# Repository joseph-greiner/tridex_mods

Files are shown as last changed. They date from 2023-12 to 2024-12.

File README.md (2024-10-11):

# Tridex Mods

Here are modifications I have made for my Tridex, I decided to gather them into a separate repository as I am not sure what should realistically be merged into the main Tridex repository.

## [Adjustable Carriages](https://github.com/joseph-greiner/tridex_mods/tree/main/adjustable_carriage)

Optional physically adjustable carriages that supports CW2 and Stealtherburner compatible hardware.

## [Docs](https://github.com/joseph-greiner/tridex_mods/tree/main/docs)

<b>frame_and_rails_calc.ods:</b> An easier to understand Tridex frame, rails, and belt calculator. Includes Misumi order numbers for extrusions.<br>
<b>parametric_panels.FCStd:</b> Parametric FreeCAD document that scales the panels for selected bed and parking sizes. Export the sketches as DXF and send off to your preferred seller.

## [Dragon Burner Cowls](https://github.com/joseph-greiner/tridex_mods/tree/main/dragon_burner_cowls)

Remix of [chirpy2605 Dragon Burner](https://github.com/chirpy2605/voron/tree/main/V0/Dragon_Burner) tool head to have identifiers on the front face.

## [Drive Frame Umbilical Mount](https://github.com/joseph-greiner/tridex_mods/tree/main/drive_frames_umbilical_mounts)

Added mounts for PG7 glands to the left and right drive frames.

## [Filament Runout Switch and Umbilical Management](https://github.com/joseph-greiner/tridex_mods/tree/main/filament_runout_umbilical_management)

Filament runout switches that mount to the upper rear frame, combined with some reverse bowden and umbilical management clips. An easy way to tame your tool head wiring and filament.

## [Front Skirts](https://github.com/joseph-greiner/tridex_mods/tree/main/front_skirts)

Addition of Revo nozzle holders and USB access to the front skirt.

## [Printer configuration](https://github.com/joseph-greiner/tridex_mods/tree/main/printer_configuration)

Full set of Klipper IDEX macros to enable full use of your printer with minimal configuration on your part. Works best with my Prusa Slicer configuration.

## [Slicer Configuration](https://github.com/joseph-greiner/tridex_mods/tree/main/slicer_configuration)

This is my current Prusa Slicer configuration, including any custom gcode that helps the macros in the printer configuration work.

## [Thick Wiper modification](https://github.com/joseph-greiner/tridex_mods/tree/main/thick_wiper_mod)

Modification for the thick wiper on the wiper arm to allow a loop of silicone instead of a block. This allows for easier adjustment for preventing ooze.

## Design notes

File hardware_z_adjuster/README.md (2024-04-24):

# Hardware z adjustment using double tap

This small modification adds hardware adjustable z height adjustment for the T1 carriage. My testing has shown it to be very consistent, even after travelling across hundreds of miles of US interstate.

## Requirements:

<ul>
  <li>The <a href="https://github.com/joseph-greiner/Double-TAP-for-Tridex">Double Tap for Tridex</a> carriages.
  <li>The tap upper for D2HW available <a href="https://github.com/VoronDesign/Voron-Tap/blob/main/STLs/Tap_Upper_D2HW_r8.stl">here</a>, installed on the the T1 tap front.</li>
  <li>The nozzle for T1 MUST be physically lower (closer to the bed) than the nozzle for T0. If your T1 nozzle is higher than T0, you can shim your hot end with a small printed part from above the heat sink, or a metal washer from below. I personally use an M4 washer between the nozzle and heat sink on my Revo setup, the spring that holds the heater keeps it trapped and not falling out if care is taken.
  <li>3 pieces of hardware you probably already have.</li>
</ul>

## Bill of Materials:
<ul>
  <li>1 - M3 heat set insert.</li>
  <li>1 - M3x12 SHCS.</li>
  <li>1 - M3x20 SHCS.</li>
  <li>Printed parts. ABS / ASA recommended, standard Voron print settings.</li>
</ul>

## Instructions:
<ul>
  <li>Install the heat set into the shuttle piece, from the large side.<br>
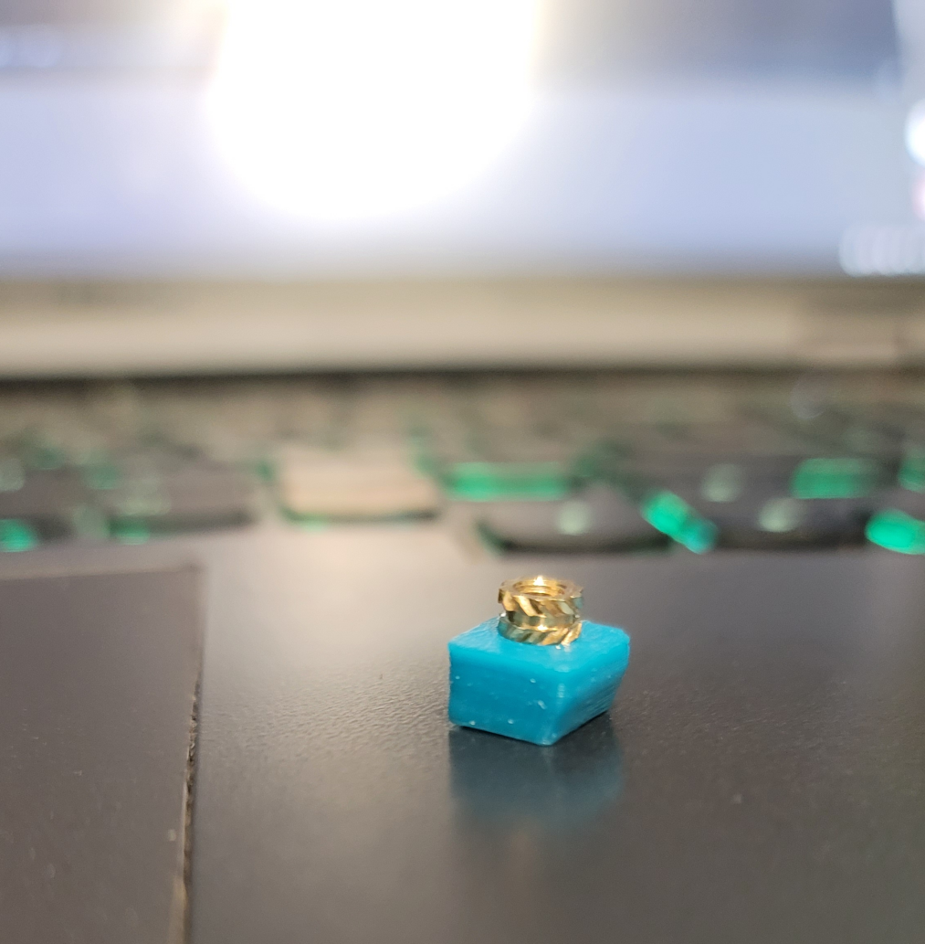
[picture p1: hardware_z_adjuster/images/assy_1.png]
    
  </li>
  <li>Screw the M3x20 fully into the housing, and continue rotating it until it rotates without too much resistance. Basically create some threads with the screw and then strip them out.<br>
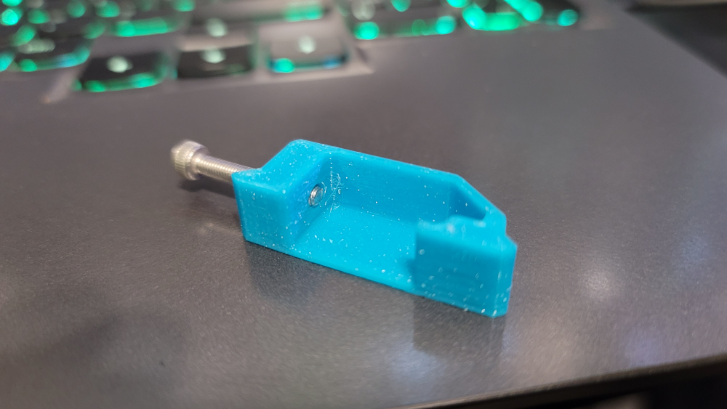
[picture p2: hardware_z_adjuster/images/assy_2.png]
    
  </li>
  <li>Install the shuttle onto the M3x20 screw. Then push the shuttle / screw assembly through the housing a couple times.<br>
      The idea behind this is a push fit of the screw into the plastic housing, it will help it not rotate while printing.<br>
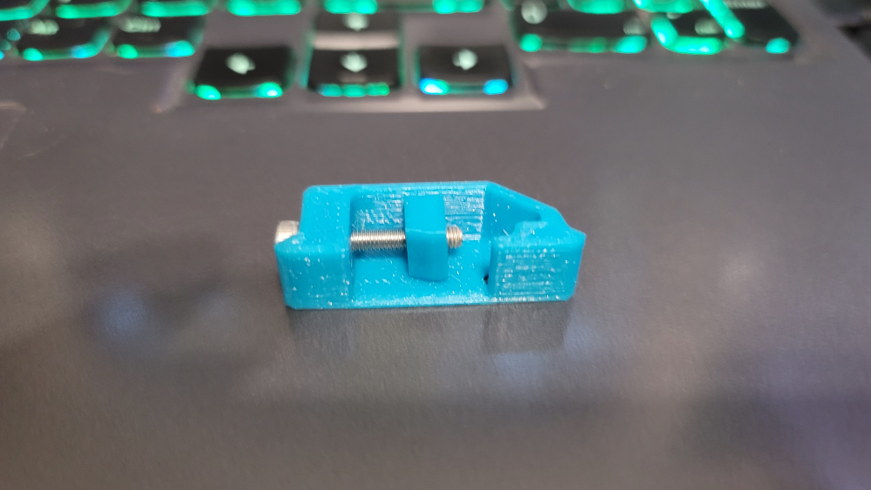
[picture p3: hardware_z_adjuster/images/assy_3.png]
    
  </li>
  <li>The shuttle should move back and forth when turning the screw, but the head of the screw should stay seated on the housing.</li>
  <li>Add the ramp to the assembly then install onto the T1 carriage using the M3x12 in the hole that the Tap switch would mount into.<br>
      The mounting screw should be secure but not tight enough to bind the adjuster.<br>
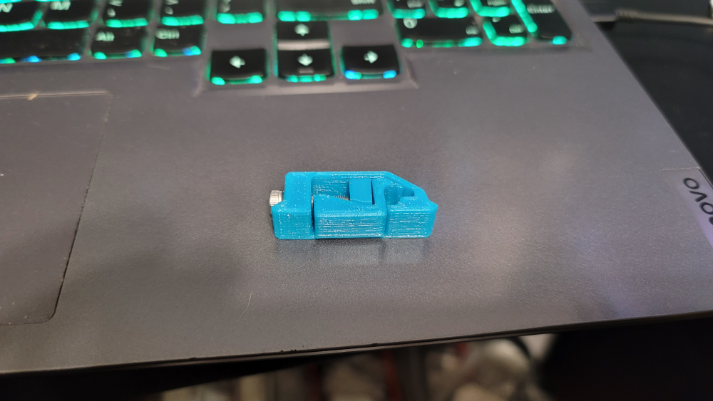
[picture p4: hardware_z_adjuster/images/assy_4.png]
    
  </li>
  
</ul>

## Images:
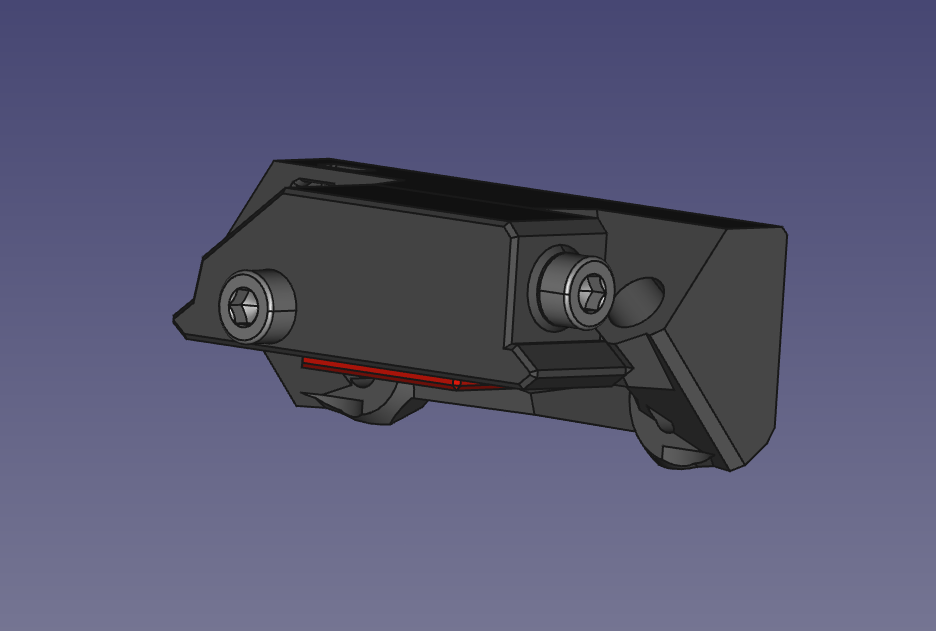
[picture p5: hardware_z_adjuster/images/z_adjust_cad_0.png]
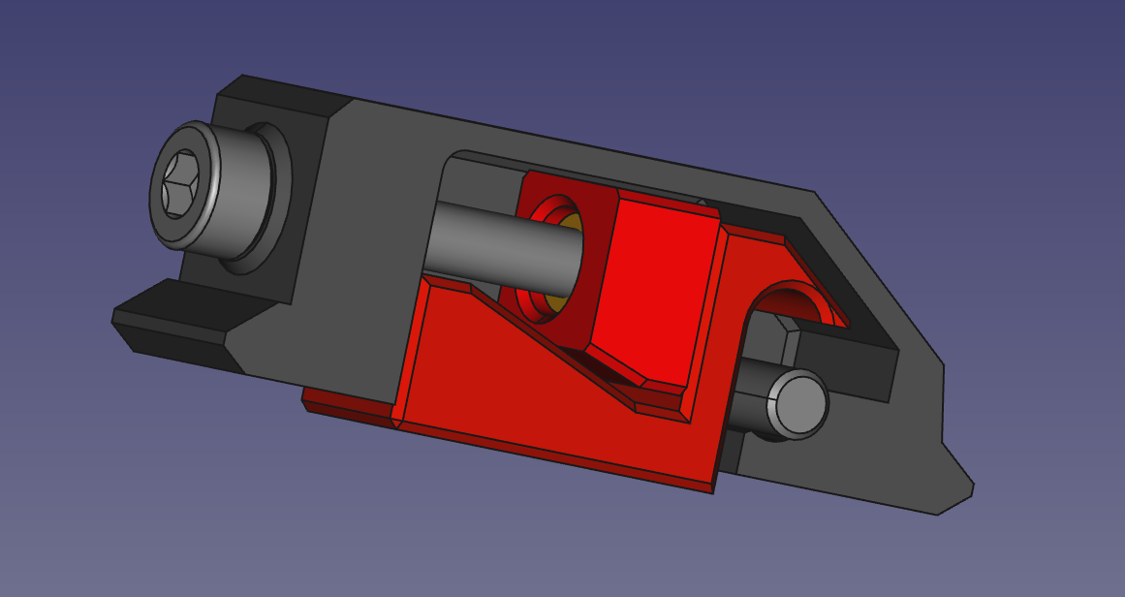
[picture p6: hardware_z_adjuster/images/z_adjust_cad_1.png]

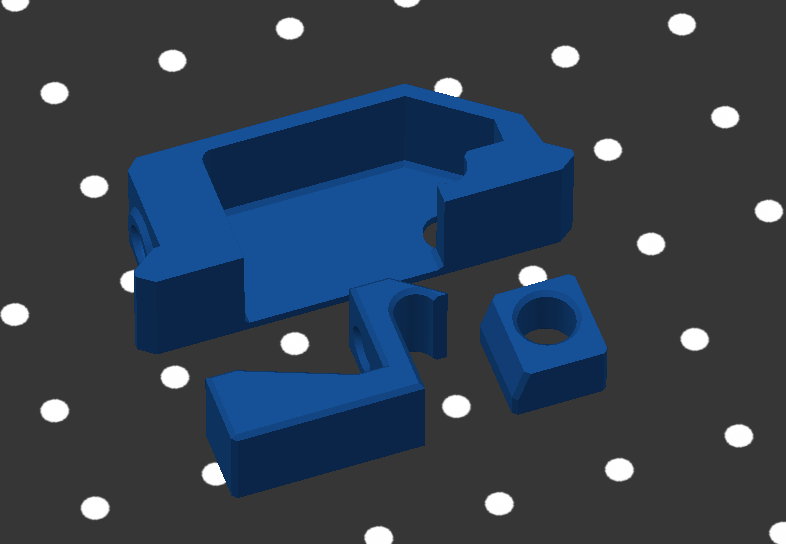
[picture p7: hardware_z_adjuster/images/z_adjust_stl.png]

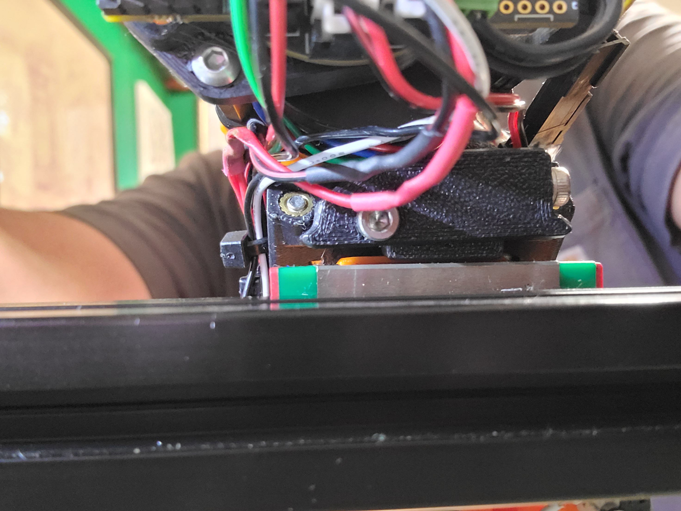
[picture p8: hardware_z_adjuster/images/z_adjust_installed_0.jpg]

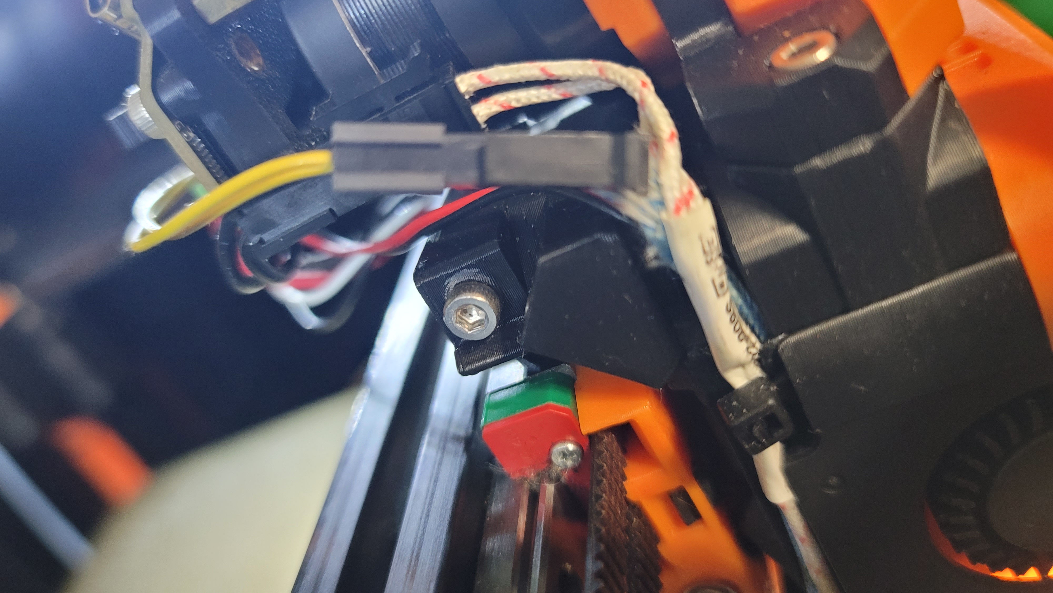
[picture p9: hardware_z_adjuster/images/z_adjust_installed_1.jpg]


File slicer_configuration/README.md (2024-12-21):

Here is the configuration I use for Prusa Slicer and Orca Slicer

# Update for December 20, 2024
Updated the slicer profiles to current releases.<br>
<ul>
    <li>Prusa Slicer: Removed custom gcode on tool change. Prusa Slicer no longer supports wipe tower location placeholders as of version 2.9.0 Alpha.</li>
    <li>Orca Slicer: Updated hacked single tool multimaterial printer to multiple tools. I will add Orca version numbers on the zip file from now on.</li>
</ul>

# Update for June 16, 2024<br>
Added Orca Slicer profiles for Primary, Copy, and Mirror modes. Hopefully the filament profiles are included. These are basic settings and get me good prints on my machine while using my printer configuration. Useable as-is or as a base for modifying for your machine.<br>

When using Copy and Mirror modes, make sure the second filament is the same as what you have in the printer, if set to one filament then it will use that for both extruders.

# Update for April 23, 2024<br>

Corrected copy and mirror mode start g-code to align with new print_start macro. Will no longer get errors when using these modes.<br>

Primary mode start g-code:<br>
<pre>
; M190 S0
; M109 S0 ; uncomment to remove set & wait temp gcode added automatically after this start gcode
print_start print_mode="PRIMARY" t0_starting_temp={first_layer_temperature[0]} t1_starting_temp={first_layer_temperature[1]} ooze_prev={ooze_prevention} initial_tool={initial_extruder}
</pre>

Copy mode start g-code:<br>
<pre>
; M190 S0
; M109 S0 ; uncomment to remove set&wait temp gcode added automatically after this start gcode
print_start print_mode="COPY" t0_starting_temp={first_layer_temperature[0]} t1_starting_temp={first_layer_temperature[1]} t0_printing_temp={temperature[0]} t1_printing_temp={temperature[1]}
</pre>
<br>

Mirror mode start g-code:<br>
<pre>
; M190 S0
; M109 S0 ; uncomment to remove set&wait temp gcode added automatically after this start gcode
print_start print_mode="MIRROR" t0_starting_temp={first_layer_temperature[0]} t1_starting_temp={first_layer_temperature[1]} t0_printing_temp={temperature[0]} t1_printing_temp={temperature[1]}
</pre>
<br>

It has 3 Tridex printers,
Primary mode, Copy mode, and Mirror mode. All have 0.4 nozzles, the only change is the start gcode and custom tool change gcode.

The bed size is 300x300. Adjust for your bed size.

There are two print profile, Quality and Speed.

bed_textures contains the images I use in Prusa Slicer for my bed textures. The PNG files are what you should use in Prusa Slicer, the SVG files are the editable source files for the textures that can be easily edited in Inkscape.

Updated December 4, 2023

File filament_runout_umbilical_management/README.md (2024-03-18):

# Filament runout Switch and umbilical management.
 This is a filament runout switch integrated into the umbilical and bowden management that I use.<p>

 Each filament switch requires the following (each):
 <ul>
    <li>2x ECAS fittings, <a href="https://www.amazon.com/Pneumatic-Connector-Extruder-Fittings-Accessories/dp/B099FG52D4/ref=sr_1_4?sr=8-4">Amazon Link</a></li>
    <li>1x microswitch, wired for normally open. This is usually the two pins next to each other above the switch button. <a href=https://www.amazon.com/DAOKI-Switch-Momentary-Button-Arduino/dp/B07YKH3TDR/ref=sr_1_9?sr=8-9>Amazon link</a></li>
    <li>1x 683ZZ bearing, <a href="https://www.amazon.com/uxcell-Bearing-Double-Shielded-Bearings/dp/B07FW18RQY/ref=sr_1_5?sr=8-5 "> Amazon Link</a>
    <li>1x bowden_mount_upper_filament_switrch printed part.
    <li>1x M3 t-nut</li>
    <li>1x M3-8 SHCS</li>
    <li>2x M2-10 SHCS</li>
 </ul>

The bowden_mount_lower only requires one M3 t-nut and one M3-8 SHCS for mounting to the frame.

 The filament switch part collects the bowden from the filament spool and the umbilical wiring from the frame. The bowden_clip parts trap the bowden tube in the smaller part and uses the bushing (printed in flexible filament) to grab the wiring. You can use a negative volume in Prusa Slicer to make the hole in the bushing the correct size for your umbilical wiring. I use 3 bushings and clips for each tool head on my setup. See images below.

<p>
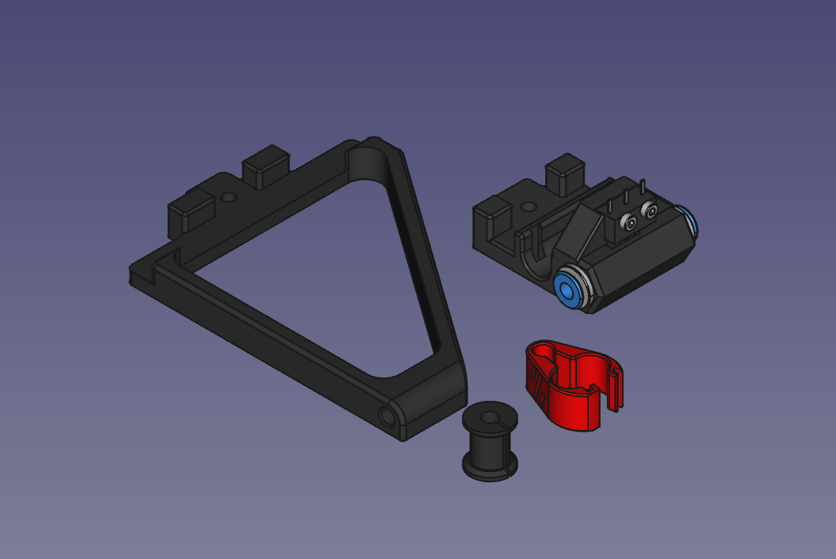
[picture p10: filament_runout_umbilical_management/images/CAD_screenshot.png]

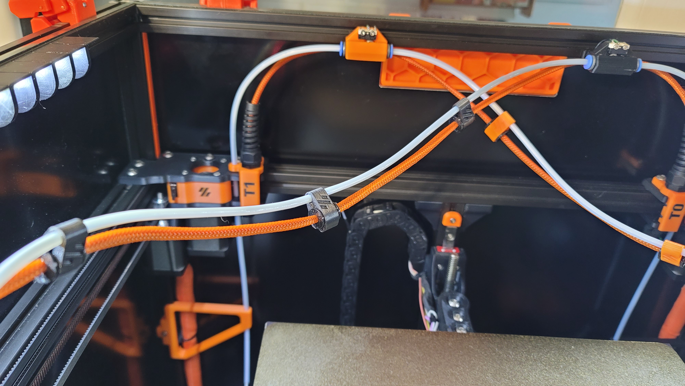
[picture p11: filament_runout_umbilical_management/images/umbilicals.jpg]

<p>
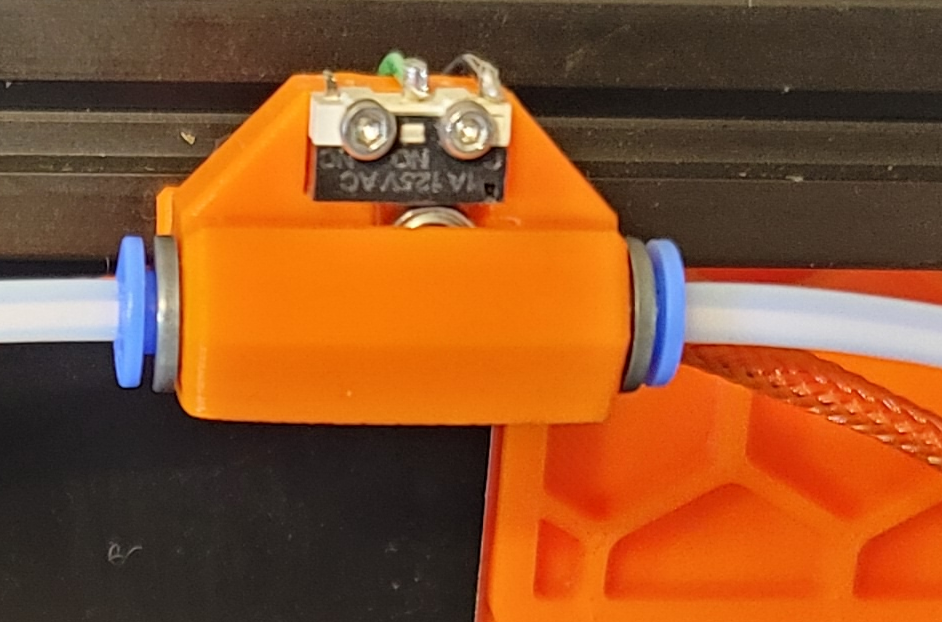
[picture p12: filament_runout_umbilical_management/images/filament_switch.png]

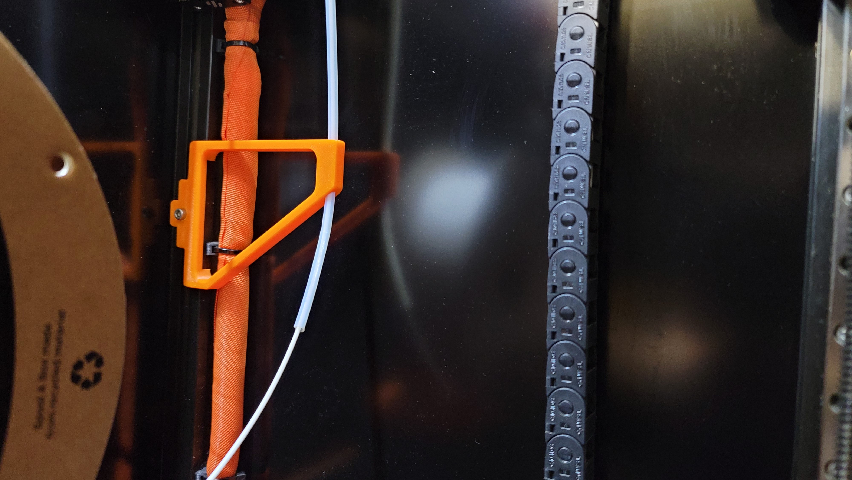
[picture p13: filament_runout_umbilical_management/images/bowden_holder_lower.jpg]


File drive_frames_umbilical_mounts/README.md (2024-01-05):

# Drive frames with umbilical mounts
 Replacement drive frames for Tridex with a PG7 mount and passthrough for a bowden tube.<p>

 Each PG7 mount piece has a blank version and a version that labels that side with the tool head number. T0 is on the right because that is the location of the x_stepper. T1 is on the left because the dual_carriage stepper is on that side. Additionally with the spools mounted on the inside of the chamber, I found it best for the bowden routing to have them setup this way. Spool on the left side goes to the tool head on the right and vice versa.<p>

 The [a]_drive_frame_mid.stl is unchanged from the standard Tridex files, but I added an insert for the Voron logo so if they are printed on a printer with multi-color abilities they can be printed that way.<p>

 Getting the inserts lined up did not work well for me when exporting raw STL files, so I lined them up in Prusa Slicer and saved the projects as .3mf files for ease of use.<p>

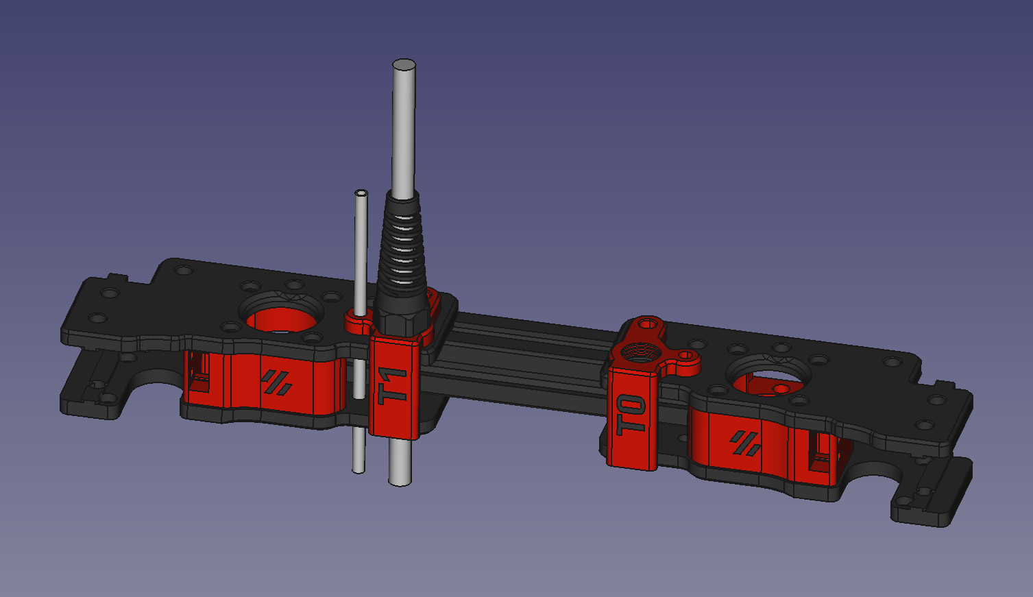
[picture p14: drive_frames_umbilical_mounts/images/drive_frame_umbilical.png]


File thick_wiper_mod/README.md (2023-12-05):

# Thick Wiper modifications
 This allows for a loop of silicone pad rather than a stack. It makes it easier to position the pad under the nozzle to prevent oozing while parked.



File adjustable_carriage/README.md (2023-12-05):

# Adjustable carriages for Tridex
 Replacement carriages for Tridex with a physical adjustment.

The mounting on the carraiges are an exact replacement for the CW2 and Stealthburner mounts, so any CW2 compatable tool head will mount on this. The carriage fits any probe mount that fits on the stock carriage. The tool mounting is approximately 5mm towards the Y minimum direction from the stock carriage. So there may be some loss of travel along the Y axis.

The carriage portion could be used with any tool mount desired, all it needs is a dovetail on the rear that slides into the carriage with a light press fit (see the CAD for dimensions). Also in order to have adjustment, a provision is needed so the lever pushes down on the MGN12 carriage.

The design works well with [Double Tap](https://github.com/ShadowSteve1/Double-TAP-for-Tridex) installed on T0 for probing, as the tool mounting plane is designed to match up with it along the Y axis.

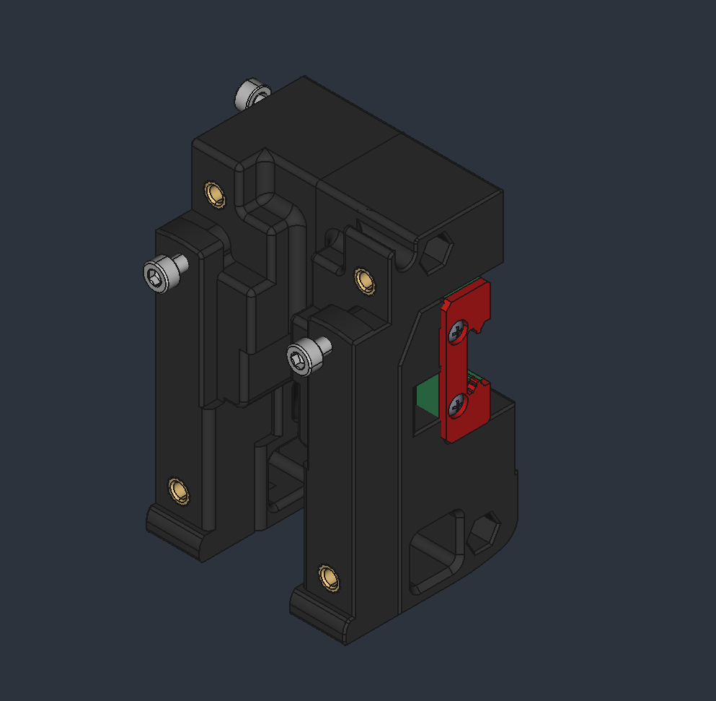
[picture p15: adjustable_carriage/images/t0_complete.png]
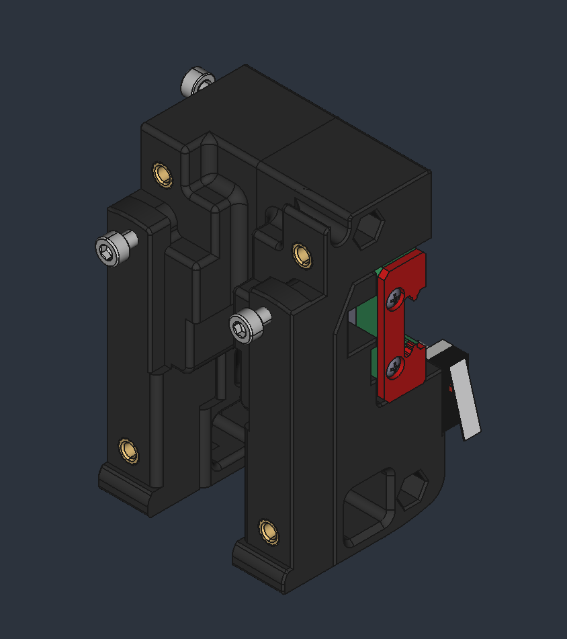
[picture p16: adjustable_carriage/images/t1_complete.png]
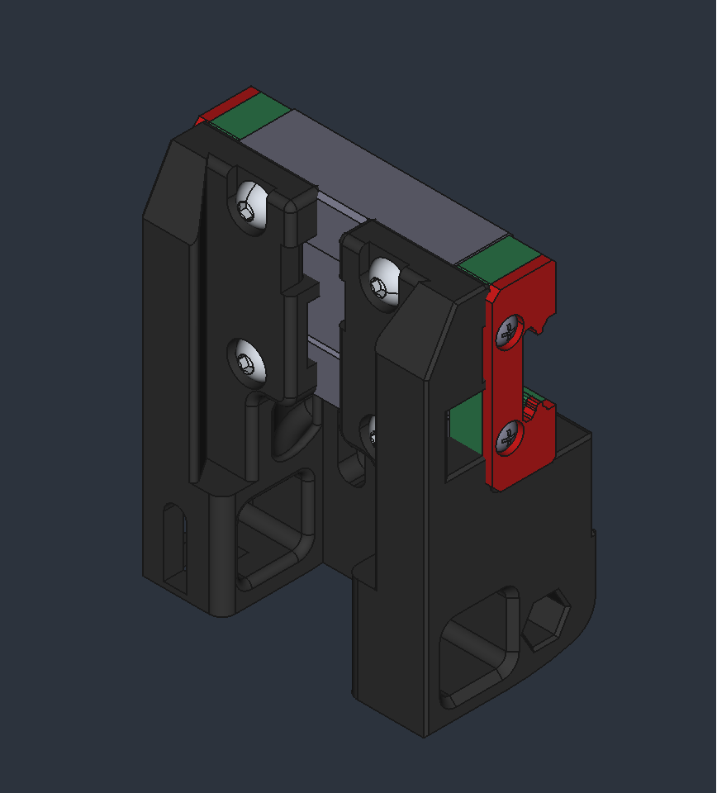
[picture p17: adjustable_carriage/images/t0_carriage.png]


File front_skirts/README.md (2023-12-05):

# Front Skirt modifications
 Two of the revo_nozzle_holder_skirt sections fit in the front of the Tridex when using Trident 250 front skirts. This takes up all the space for a 250 build Tridex, a 300 build will have a gap large enough for the USB skirt panel. This allows USB extensions to be used to bring the USB from the raspberry Pi out to the skirt for easy access.



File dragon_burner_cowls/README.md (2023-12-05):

# Dragon Burner Cowls
 Remix of [chirpy2605 Dragon Burner](https://github.com/chirpy2605/voron/tree/main/V0/Dragon_Burner) tool head to have identifiers on the front face.

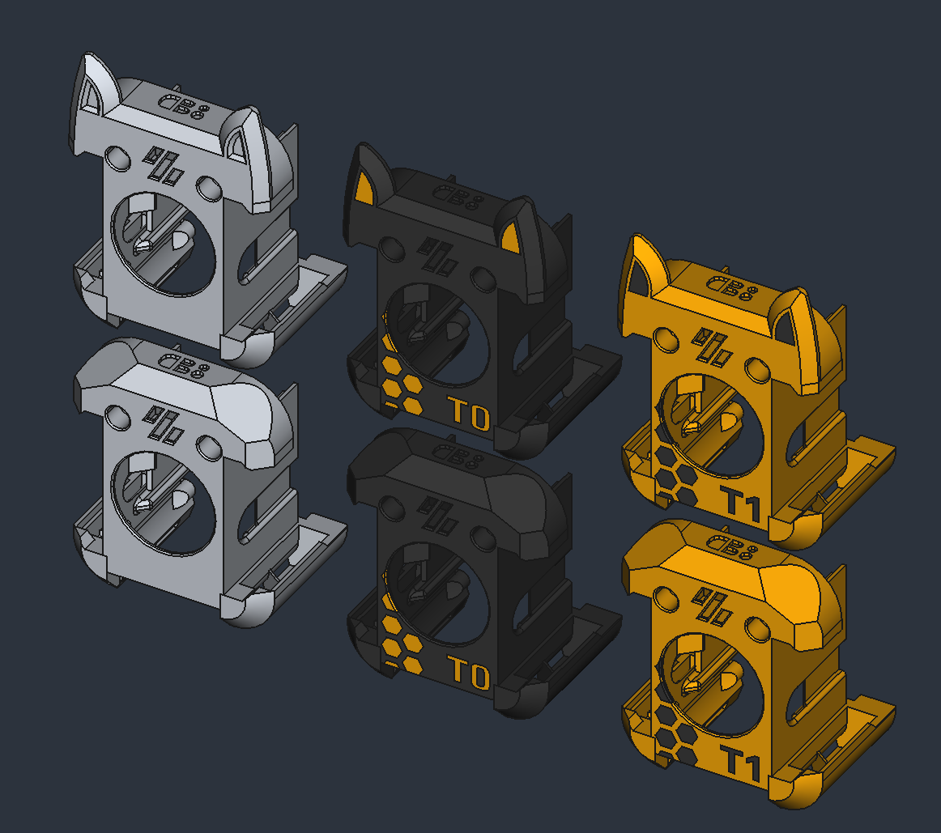
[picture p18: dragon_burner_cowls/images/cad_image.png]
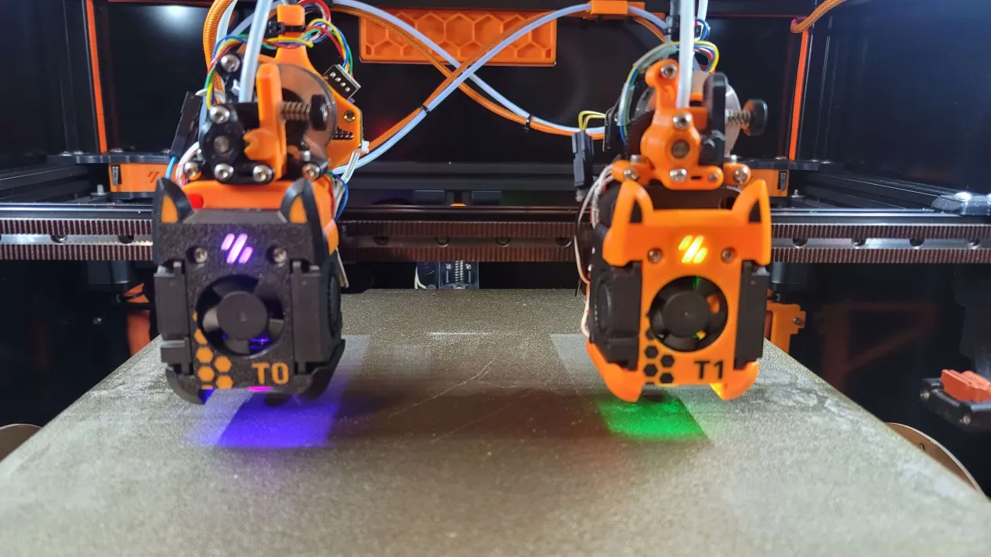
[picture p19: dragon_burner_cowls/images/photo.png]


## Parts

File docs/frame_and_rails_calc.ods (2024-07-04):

Change green cells to desired bed size, Z height, tool width, and parking area in mm
Standard Voron Bed size: | 250 | 250 / 300 / 350 |  |  | Tool head limits:
Z height: | 250 |  |  |  | T0 min X: | -50
Tool Head Width: | 75 | Stealthburner is about 75mm wide |  |  | T0 max X: | 225
Parking Area: | 50 | Standard Parking area is 50mm |  |  | T1 min X: | 25
 |  |  |  |  | T1 max X: | 300
 |  |  |  | Tool head usable area |  | 200
X-Axis MGN12 Rail length: | 400 | mm | Recommend less than 500mm
Y-Axis MGN9 Rail length: | 300 | mm |  |  |  | Total Printer Size (WxDxH):
Z-Axis MGN9 Rail length: | 300 | mm |  |  |  | 510mm Wide (X)
Minimum Belt Length to Buy: | 6 | m | Rounded up to the next whole meter |  |  | 410mm Deep (Y)
 |  |  |  |  |  | 580mm High (Z)
Frame Pieces to Order:
Where used | Qty | Extrusion Type | Length (mm) | Axis | Modifiers | Misumi Order Number
Horizontal (Width-X) | 3 | HFSB5-2020 | 470 | x | TPW | HFSB5-2020-470-TPW
Horizontal (Depth-Y) | 6 | HFSB5-2020 | 370 | y | TPW | HFSB5-2020-370-TPW
Bottom Rear | 1 | HFSB5-2020 | 470 | x | TPW-AH235 | HFSB5-2020-470-TPW-AH235
X axis | 1 | HFSB5-2020 | 430 | x |  | HFSB5-2020-430
Gantry Rear Crossbar | 1 | HFSB5-2020 | 340 | x |  | HFSB5-2020-340
Bed (Width-X) | 1 | HFSB5-2020 | 470 | x | AH235 | HFSB5-2020-470-AH235
Bed (Depth-Y) | 1 | HFSB5-2020 | 232 | y | LTP | HFSB5-2020-232-LTP
Verticals | 4 | HFSB5-2020 | 500 | z | LCP-RCP-AV360 | HFSB5-2020-500-LCP-RCP-AV360
Center Z Vertical | 1 | HFSB5-2020 | 330 | z | LTP | HFSB5-2020-330-LTP
 |  |  |  |  | Extrusion Modifier Legend
 |  |  |  |  | TPW | Tap both ends, M5x0.8
 |  |  |  |  | AH | Access hole, horizontal
 |  |  |  |  | LTP | Left end tap, M5x0.8
 |  |  |  |  | LCP | Left blind joint holes
 |  |  |  |  | RCP | Right blind joint holes
 |  |  |  |  | AV | Access hole, vertical

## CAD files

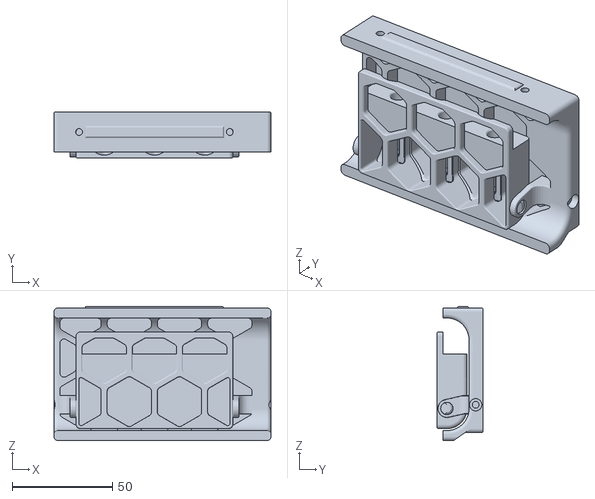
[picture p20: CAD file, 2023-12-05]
front_skirts/STL/revo_nozzle_holder_full.stl
108.0 x 23.0 x 66.8

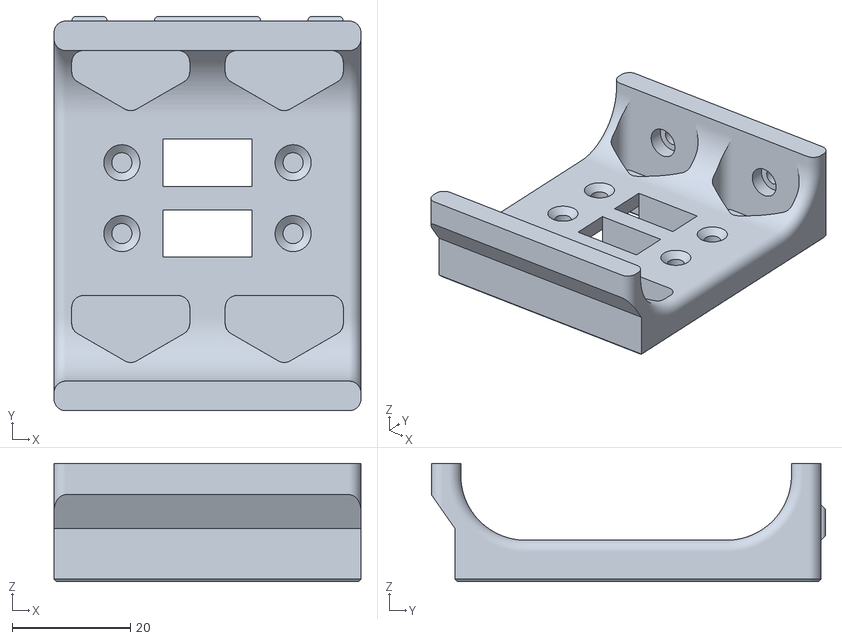
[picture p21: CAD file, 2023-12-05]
front_skirts/STL/usb_panel_full.stl
52.0 x 66.8 x 20.0

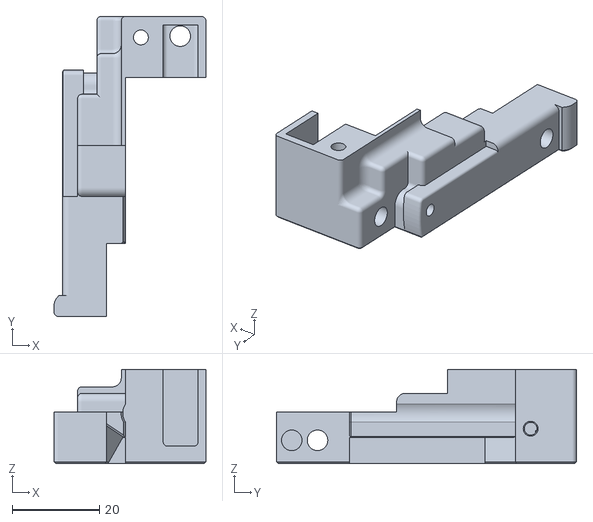
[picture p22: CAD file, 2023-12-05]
adjustable_carriage/STL/ac_tool_mount_left.stl
34.8 x 68.7 x 21.6

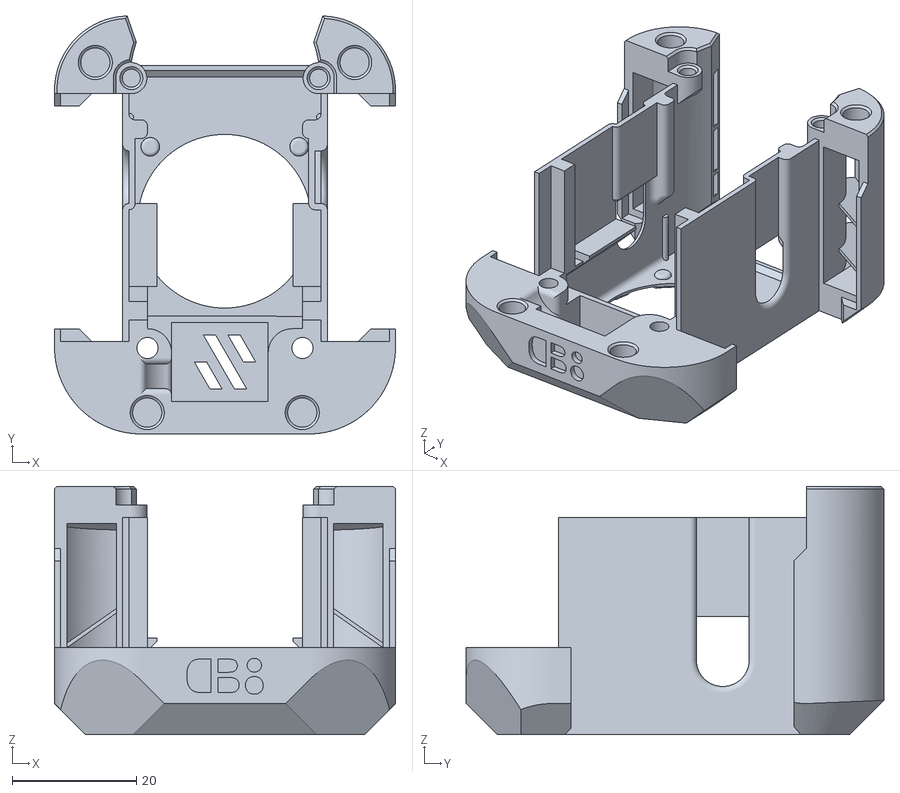
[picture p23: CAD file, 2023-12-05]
dragon_burner_cowls/STL/t0_cowl.stl
55.0 x 67.4 x 40.0

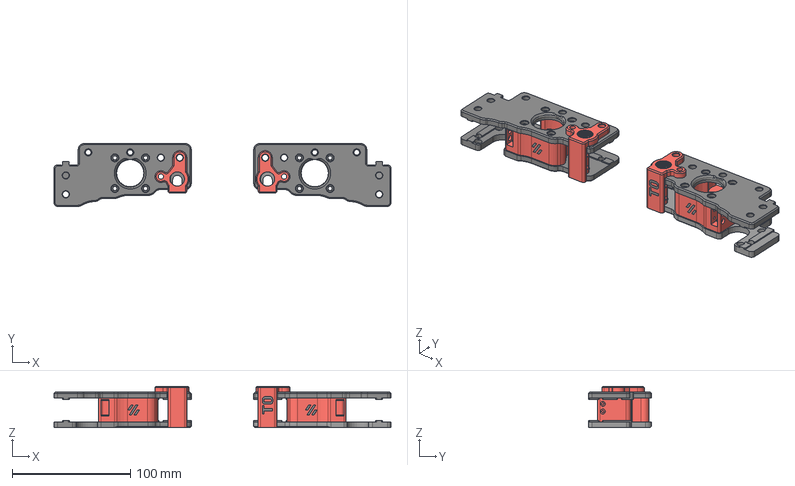
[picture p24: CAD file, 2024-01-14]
drive_frames_umbilical_mounts/CAD/drive_frame_umbilical_mount.step
285.2 x 53.3 x 35.0 mm
drive_frame_left_upper
drive_frame_left_lower
[a]_drive_left_mid
t1_text
voron_logo_insert_left
pg7_mount_left
pg7_mount_left_t1
voron_logo_insert_right
[a]_drive_right_mid
t0_text
drive_frame_right_lower
drive_frame_right_upper
[a]_pg7_mount_right
[a]_pg7_mount_right_t0

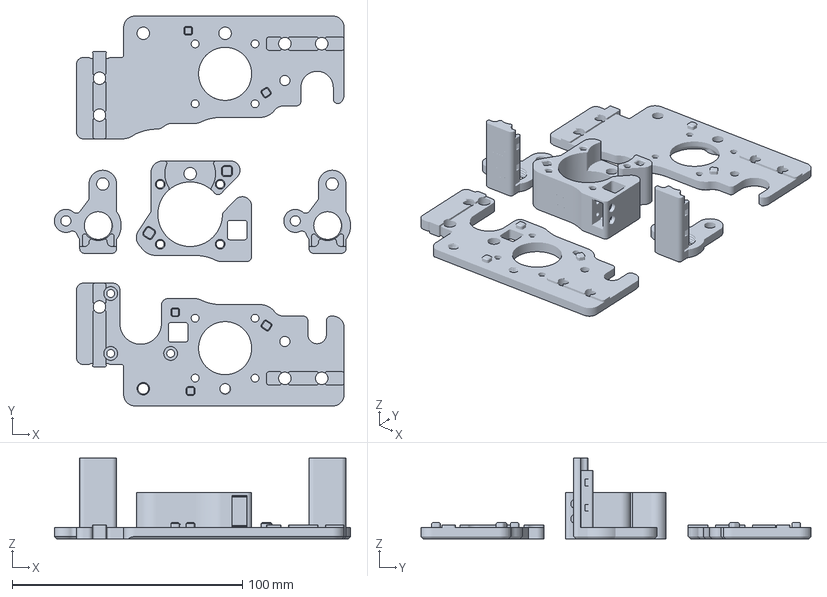
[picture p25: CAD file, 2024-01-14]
drive_frames_umbilical_mounts/STL/drive_frame_umbilical_mounts_right.3mf
128.5 x 169.2 x 35.0 mm

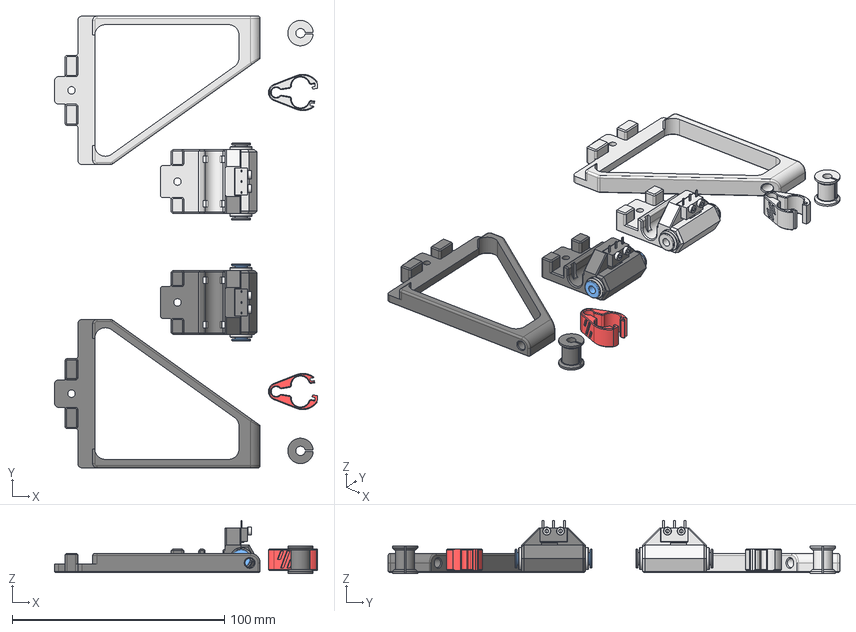
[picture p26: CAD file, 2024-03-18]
filament_runout_umbilical_management/CAD/filament_runout_bowden_management.step
124.0 x 213.0 x 25.0 mm
bowden_spool_mount_lower
[flex]_bowden_clip_bushing
[a}_bowden_clip
bowden_mount_upper_filament_switrch
ECAS04 Bowden Collet004
ECAS04 Bowden Collet005
ECAS04 Bowden Collet
ECAS04 Bowden Collet001
MainBody001
Button001
M2x10-Screw x 2
bowden_management001 (Mirror #1)

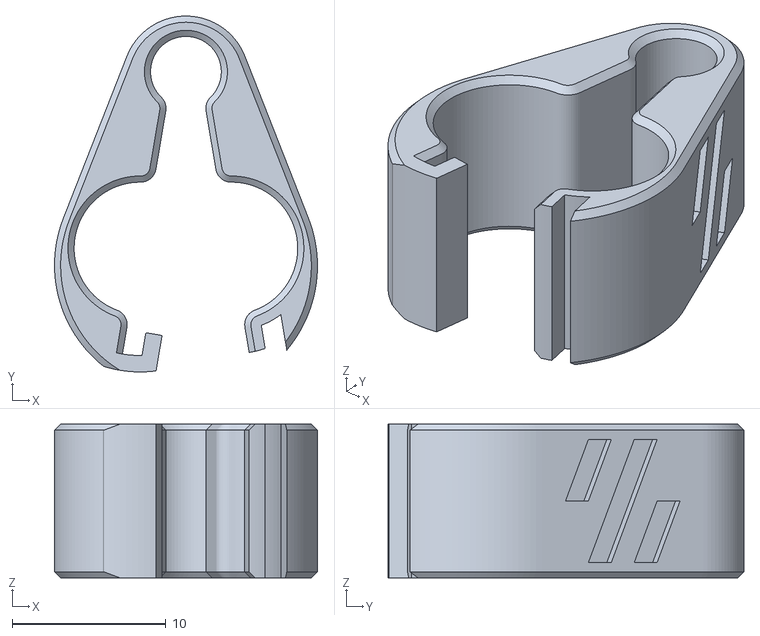
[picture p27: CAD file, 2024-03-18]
filament_runout_umbilical_management/STL/[a]_bowden_clip_x3.stl
17.1 x 23.1 x 10.0

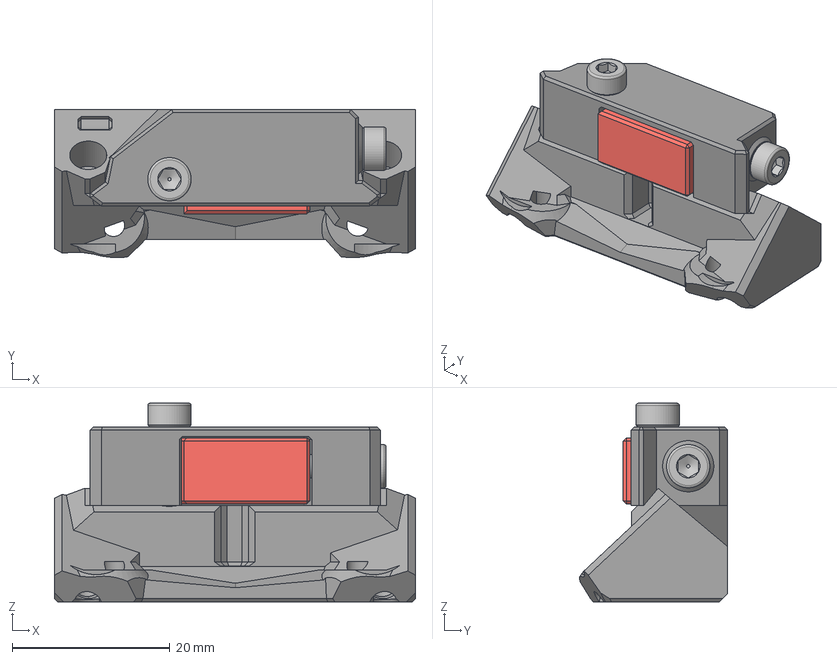
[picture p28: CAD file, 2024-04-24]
hardware_z_adjuster/CAD/hardware_z_adjuster.step
45.8 x 18.8 x 25.2 mm
tap_upper_D2HW
z_adjuster_housing
z_adjuster_shuttle
z_adjuster_ramp
M3x4-Insert
M3x20-Screw
M3x12-Screw

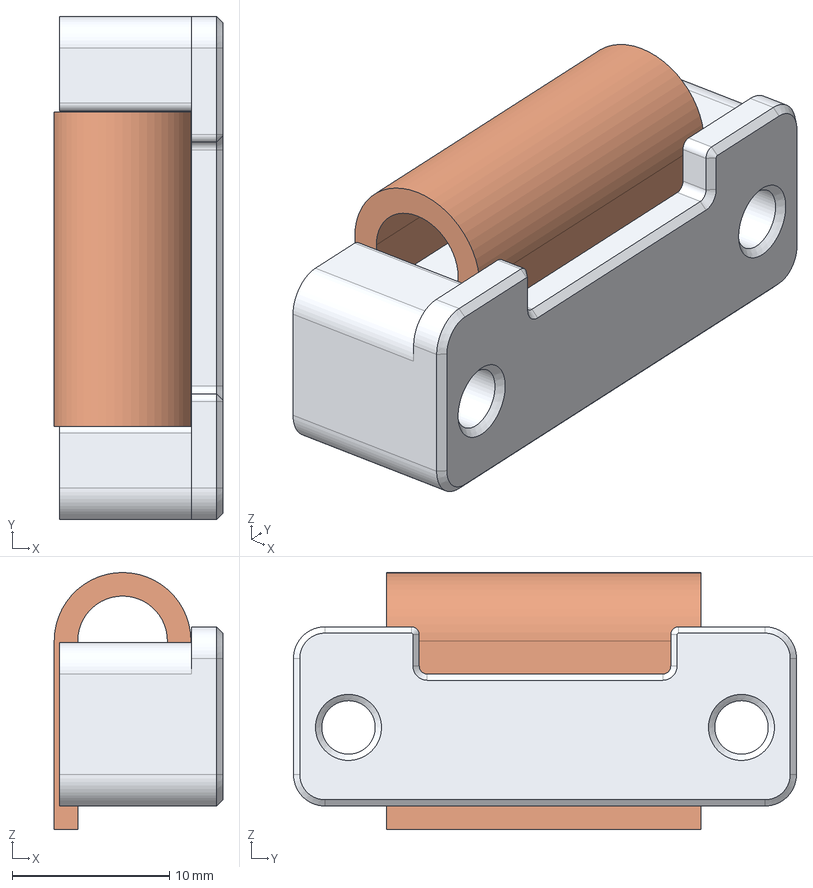
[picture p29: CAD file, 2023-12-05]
thick_wiper_mod/CAD/thick_wiper_mod.step
10.7 x 32.0 x 16.4 mm
Thick_Wiper_Mod
Wiper_Spacer
Silicone_pad

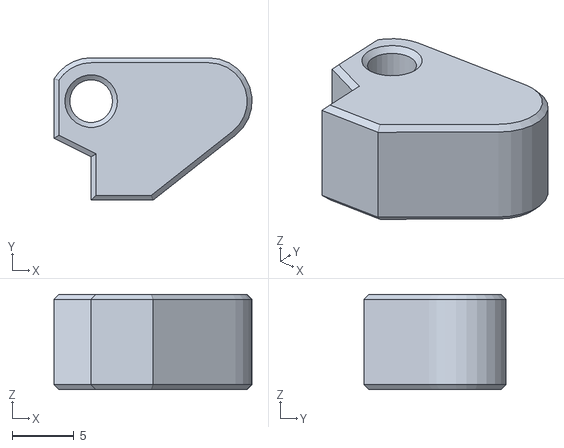
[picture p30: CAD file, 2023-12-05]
adjustable_carriage/STL/ac_lever.stl
16.0 x 11.5 x 7.70

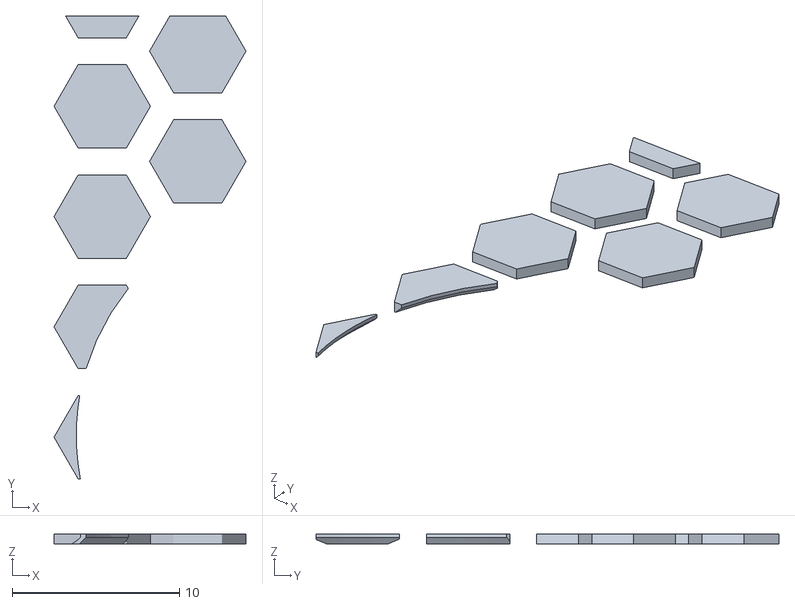
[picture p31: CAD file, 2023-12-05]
dragon_burner_cowls/STL/t1_cowl_hex_insert.stl
11.5 x 27.7 x 0.6

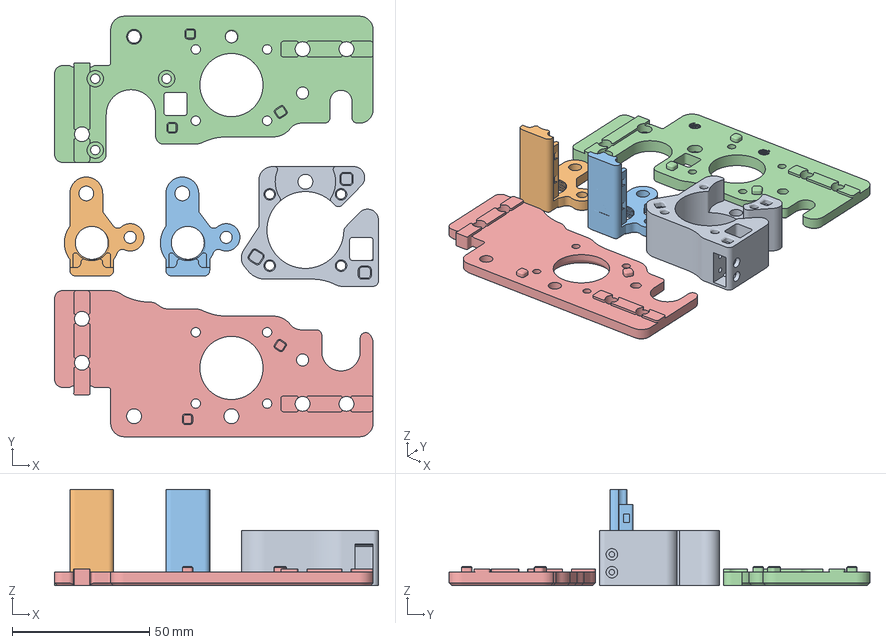
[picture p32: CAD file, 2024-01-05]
drive_frames_umbilical_mounts/STL/drive_frame_umbilical_mounts_left.3mf
118.1 x 153.3 x 35.0 mm
[a]_drive_frame_left_mid
[a]_pg7_mount_left.stl
[a]_pg7_mount_left_t1
drive_frame_left_lower.stl
drive_frame_left_upper.stl

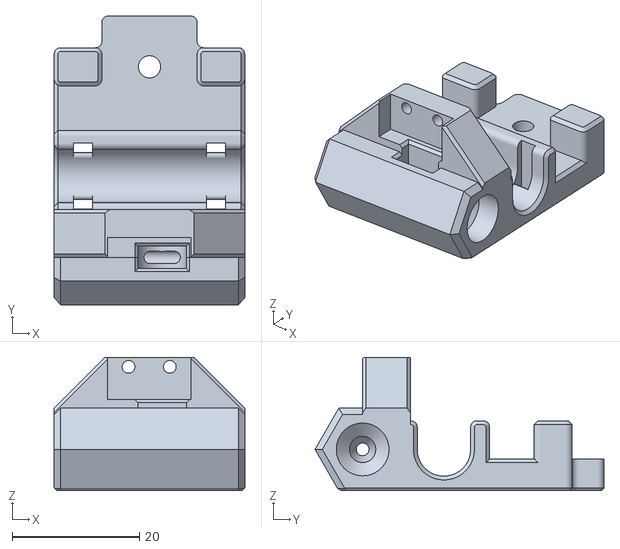
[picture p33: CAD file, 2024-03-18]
filament_runout_umbilical_management/STL/bowden_mount_upper_filament_switrch_left.stl
30.0 x 45.5 x 21.0

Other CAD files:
docs/parametric_panels.FCStd
front_skirts/CAD/usb_panel.step
front_skirts/STL/revo_nozzle_holder_skirt.stl
adjustable_carriage/STL/t1ac_carriage_left.stl
adjustable_carriage/STL/ac_tool_mount_right.stl
adjustable_carriage/STL/t0ac_carriage_left.stl
adjustable_carriage/STL/t0ac_carriage_right.stl
adjustable_carriage/STL/t1ac_carriage_right.stl
dragon_burner_cowls/STL/t0_cat_cowl.stl
dragon_burner_cowls/STL/t0_cat_cowl_ear_insert.stl
dragon_burner_cowls/STL/t0_cat_cowl_hex_insert.stl
dragon_burner_cowls/STL/t0_cat_cowl_text.stl
dragon_burner_cowls/STL/t0_cowl_text.stl
dragon_burner_cowls/STL/t1_cat_cowl.stl
dragon_burner_cowls/STL/t1_cat_cowl_ear_insert.stl
dragon_burner_cowls/STL/t1_cat_cowl_hex_insert.stl
dragon_burner_cowls/STL/t1_cat_cowl_text.stl
dragon_burner_cowls/STL/t1_cowl.stl
dragon_burner_cowls/STL/t1_cowl_text.stl
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

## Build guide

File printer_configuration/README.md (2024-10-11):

# Printer Configuration

These are my current configuration and macros for stock Klipper based IDEX machines. When combined with my slicer configuration, these macros allow full printing capabilities with your printer with little to no modifications.

## Printing modes:

Single tool prints (T0 or T1)<br>
Dual material or dual color printing with both tool heads.<br>
Copy and Mirror mode printing with whatever materials are selected in the slicer.<br>

## Multiple tool head change modes:

<b>Swap:</b> Quickest tool change mode, both tool heads move at the same time. (Ported from Vcore IDEX macros by Helge Keck)<br>
<b>Classic:</b> Original Tridex tool change, one tool head moves at a time.<br>
<b>Ooze Prevention</b> If nozzles are cooled down when not actively printing, keeps the tool head in the parking area until printing temperatures are reached<br>
When ooze prevention is checked from within Prusa Slicer, this mode is automatically selected, no changes to your printer configuration needs to be done.<br>

## Tool head offsets adjustable without restarting Klipper

Macros are available that allow adjusting the tool head offsets during a print (X, Y, and Z supported).<br>
Macros automatically save the new offsets so they will be kept after Klipper restarts.

## Primary, Copy, and Mirror modes fully supported

## Support for Inductive, Klicky, and Double Tap bed probing with T0

## Support for individual tool head LED activation / colors / effects.

## Filament runout and rollover support

All config files are fully commented and helps walk you through what needs changed and what does not need changed. If you set your board pins, end stops and probe properly. The macros just work.

# Update for October 10, 2024:
FIXED - Move out of range homing if T1 left active and Y offset was negative. Updated Klicky and IDEX homing overrides.<br>
FIXED - Commented out chamber thermistor by request... No more ADC out of range errors when you don't have one installed.<br>
FIXED - Added config_reference.md file.<br>

# Update for April 23, 2024:

Improved swap tool change macros. Pulled tool head locations from a better place, simplified the math for the tool change.<br>
Updated comments in idex_variables.cfg 

# Update for March 27, 2024:

Improved comments and examples throughout all macro files. <br>
Moved filament sensor definitions and macros to filament_macros.cfg. Makes them more modular and easy to use if desired.<br>
Added places in the print_start for Stealthburner macro calls.<br>
Added support for M601 - Pause at layer from the slicer.<br>
Added some support for M600 with 2 modes:
<ul>
  <li>Default behavior should be similar to other printers. When M600 is called the print pauses and prompts the user to unload, then load new filament. Once the filament is purged to the users satisfaction, they click resume and the print continues.</li>
  <li>Optional behavior, at any time M600 can be called with "M600 CHANGE=1" to initiate a filament rollover during a print. Additionally, there is a variable in the FILAMENT_VARS macro that if set will have M600 always have this behavior.</li>
  <li>NOTE: this is not a full implementation of the M600 macro from Marilin, it triggers on the active extruder when used with the default behavior. If care is used when applying it in the slicer then there should be no issues. If you find any, feedback is always welcome.</li>
</ul>

Added variables in FILAMENT_VARS for length of filament to continue to print after the sensor is triggered. The distance from the extruder to filament sensor is a good start.<br>
Added a timer variable for how often Klipper will check extruded filament since runout switch triggered. Shorter time, more accurate counting, but may block printing movements. 5 seconds has proved reliable in my testing.<br>

# Update for March 17, 2024:

Improved print_start:

  <ul>
    <li> Fewer and smarter tool changes.</li>
    <li> Pre-heat for the print over parking areas to prevent oozing.</li>
    <li> Smarter filament purging, only purges used tool. Purges first tool used in the print last</li>
    <li> If z offset for T1 is set to 0.0, can purge both tool heads at the same time.</li>
    <li> Will not re-home or perform z_tilt adjust if already performed.</li>
    <li> Supports current Klipper adaptive bed mesh.</li>
    <li> Better support for the following printing situations:</li>
    <ul>
        <li> T0 only prints.</li>
        <li> T1 only prints.</li>
        <li> T0 start and T1 prints.</li>
        <li> T1 start and T0 prints.</li>
        <li> Ooze prevention prints, with T0 or T1 as the starting tool head.</li>
        <li> Copy and Mirror mode printing.</li>
    </ul>
    <li> Better print starting if T1 left as the active extruder.</li>
    <li> Better print starting if last print was COPY or MIRROR mode.</li>
  </ul>
  
Improved tool change macros:

  <ul>
    <li>Fixed z_hop for tool change.</li>
    <li>Can now use the T0 and T1 macros if the printer is not homed to change active tool head. Makes filament loading and unloading a little easier.</li>
  </ul>

Improved save_config support:

  <ul>
   <li>Moved hot end PID settings into printer.cfg so when tuning you can save_config and it will not error. (thanks Old Guy Melts Plastic)</li>
  </ul>

Added Filament runout sensor support:

  <ul>
   <li>Loading filament macro added.</li>
   <ul>
      <li>When filament is inserted, will heat the corresponding tool to a default temperature if not heated.</li>
      <li>Otherwise will advance the filament after a configurable delay.</li>
   </ul>
   <li>Filament rollover supported - if one tool head runs out of filament then the other tool will finish the print.</li>
  </ul>

## !!IMPORTANT!! -- New Prusa Slicer Start G-code for PRIMARY mode printing:
    print_start print_mode="PRIMARY" t0_starting_temp={first_layer_temperature[0]} t1_starting_temp={first_layer_temperature[1]} ooze_prev={ooze_prevention} initial_tool={initial_extruder}

# Update for January 1, 2024:

Bugfix - corrected T1 offset adjustment macros. fixed z offset compounding error. Offsets now correctly update when T1 is active.

# Update for December 9, 2023:

Bugfix - preferred_tool_change was not loaded at klipper startup, corrected this.<br>
Feature - added a macro to view the current offsets for T1, it will print them to the console.

# Update for December 4, 2023:

Offsets save and load automatically to idex_variables.cfg<br>
Removed and re-organized variables from IDEX_mode.cfg<br>
Removed un-necessary tool changes from the print_start macro, especially if only using T1 in a print.<br>
added T1 Z offset macros.

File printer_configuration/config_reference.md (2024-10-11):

# This file contains explanations for the variables used in the idex_mode.cfg

# [save_variables]
# This is the location and name of the file used to store variables that can be altered without restarting Klipper.
# The variables stored here are X, Y, and Z offsets as well as the tool change method.
# Tool change methods are SWAP, CLASSIC, and OOZE_PREV. Must be in all CAPS. Default is CLASSIC change.

filename: ~/printer_data/config/idex-variables.cfg

# [gcode_macro DC_VARS]
# Variables for safe homing, set to z_endstop location pin OR safe location when using TAP.
variable_homing_safe_x: 150
variable_homing_safe_y: 150
# This feedrate is in mm per minute.
variable_homing_feedrate: 12000

# Distance from end of axis to park the tool head, needed for x/y offsets, default: 3.
# This value must be greater than the X offset between tool heads in order to avoid move out of range errors.
variable_park_distance: 3

# Copy and mirror mode start location for T0, T1 start will be calculated off these values.
# For copy mode, X for T1 will be the bed width / 2 plus the variable_copy_start_x value.
# For mirror mode, X will be the bed width minus the variable_copy_start_x value.
# Y and Z positions are shared by both tool heads with no change.
# This position is where to start the syncronization between the tool heads.
# I recommend placing it near the ending location for your T0 purge.
variable_copy_start_x: 5
variable_copy_start_y: 5
variable_copy_start_z: 5

# Print cooling fans names from your tool head configurations.
variable_fan0: 'print_cooling_t0'
variable_fan1: 'print_cooling_t1'

## Autopark parameters:
## default autopark: 0:inactive - 1:active.
# autopark = 1 will park the tool head during a tool change.
# 0 will just change to the other tool head without moving the other tool head out of the way.
# you are expected to park the inactive manually or with custom gcode.
variable_autopark: 1
# z_hop is how far you want the z to change during a tool change.
variable_z_hop: 1

# Movement speed after a tool change when restoring the gcode_state.
# This value is in mm per second.
variable_movespeed: 250
# How fast do you want to change the tool heads. The printer max_velocity will override this if you try and move too fast.
# Feedrate is in mm per minute.
variable_feedrate: 20000

# Nozzle Scrub / Purge
# Scrub the Nozzle: 1 = Yes, 0 = No
variable_scrub: 1
# How many times to scrub the nozzle, default 5
variable_scrubs: 5
# How fast to move the toolhead in mm per minute, default 3000
variable_prep_spd_xy: 3000
# Extra purging when scrubbing the nozzle, default: 0
variable_purge_length: 0
# How fast to purge the extruder, value is mm per minute. Default: 150
variable_purge_spd: 150
# How far to retract after purging to prevent oozing, default: 0
variable_purge_ret: 0
# How long to pause and wait for oozing in seconds. Default: 1
variable_ooze_dwell: 1
# What is the minimum viable purging temperature in celsius, default 200.
variable_purge_temp_min: 200

#####################################################################
#   Variables below here are set in idex-variables.cfg
#   Don't bother changing these in IDEX_mode.cfg, they will be overridden
#####################################################################

# How tool changes should be done, valid values are:
# SWAP Moves both tool heads at the same time, quickest tool change option.
#      Works best with the following custom g-code added to Tool Change in your slicer:
#      {if wipe_tower}
#      G0 X{wipe_tower_x} Y{wipe_tower_y} F{travel_speed*60} ;move to wipe tower before toolchange
#      {endif}
# CLASSIC Moves tool heads individually, classic Tridex behavior. This is the default value
# OOZE_PREV During tool change, leaves the tool over the parking area while the nozzle re-heats.

# FOR ALL TOOL CHANGE METHODS THE FULL CAPS ARE REQUIRED.

# Set the preferred_tool_change in the idex-variables.cfg to one of the following values:
# preferred_tool_change = 'SWAP'
# preferred_tool_change = 'CLASSIC'
# preferred_tool_change = 'OOZE_PREV'

# Variables to store the tool head offsets, leave a 0.0
# Set your offsets in idex-variables.cfg
variable_offset_x: 0.0
variable_offset_y: 0.0
variable_offset_z: 0.0
# These variables are for the tool change method, do not edit
# Set your preferred tool change in idex-variables.cfg
variable_swap_toolheads: 0
variable_immediate_move: 1
# Copy and mirrror mode T1 temperatures - do not edit, these are sent over by the slicer.
# They will be used during a print start.
variable_t0_copy_mirror_temp_start: 0
variable_t1_copy_mirror_temp_start: 0
variable_t0_copy_mirror_temp_print: 0
variable_t1_copy_mirror_temp_print: 0

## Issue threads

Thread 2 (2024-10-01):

docs/Config_Reference.md is missing(?)

YesterdaysCoffee, 2024-10-01:
the file docs/Config_Reference.md is missing, it was referenced in IDEX_mode.cfg

I'm working on getting your IDEX macros to work with my TrideX-17.

thanks,
Mac McCaskie

joseph-greiner, 2024-10-11:
added a config_reference.md in the printer_configuration folder

Closed 2024-10-11.

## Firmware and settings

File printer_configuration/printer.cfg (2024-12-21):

# This file contains common pin mappings for the BigTreeTech Octopus V1.1
# To use this config, the firmware should be compiled for the STM32F446 with a "32KiB bootloader"
# Enable "extra low-level configuration options" and select the "12MHz crystal" as clock reference

# after running "make", copy the generated "klipper/out/klipper.bin" file to a
# file named "firmware.bin" on an SD card and then restart the OctoPus with that SD card.

# See docs/Config_Reference.md for a description of parameters.

## DOOM / Voron Design Tridex 250/300/350mm BigTreeTech OctoPus V1.1 TMC2209 UART + two BigTreeTech EBB36 V1.2 CAN boards config

## *** THINGS TO CHANGE/CHECK: ***
## MCU paths / CAN bus UUID's           [mcu] section
## Thermistor types                     [extruder] and [heater_bed] sections - See https://www.klipper3d.org/Config_Reference.html#common-thermistors for common thermistor types
## Leadscrew Rotation Distance          [stepper_z], [stepper_z1], [stepper_z2]
## Z Endstop Switch location            IDEX_mode.cfg [gcode DCVARS] section
## Z Endstop Switch  offset for Z0      [stepper_z] section
## PID tune                             [extruder] and [heater_bed] sections
## Probe pin                            [probe] section
## Fine tune E steps                    [extruder] sections in toolboard_0.cfg and toolboard_1.cfg

##--------------------------------------------------------------------
## !!! Lines between the dashed lines need to be looked at and configured !!!
##--------------------------------------------------------------------

[include mainsail.cfg]
# [include fluidd.cfg]
[include IDEX_mode.cfg]
[include macros.cfg]
[include toolboard_0.cfg]
[include toolboard_1.cfg]
##   Uncomment the correct file for your bed probe
##   dockable probes use klicky-probe-for-VT.cfg
##   all other probes use homing_override_for_idex.cfg
##--------------------------------------------------------------------
#[include klicky-probe-for_VT.cfg]
#[include homing_override_for_idex.cfg]
##--------------------------------------------------------------------
#[include stealthburner_leds.cfg]
#[include filament_macros.cfg]

#####################################################################
#   Printer mainboard 
#####################################################################

[mcu]
##  Obtain definition by "ls -l /dev/serial/by-id/" then unplug to verify
##--------------------------------------------------------------------
serial: /dev/serial/by-id/xxxxxx
restart_method: command
##--------------------------------------------------------------------

## See https://canbus.esoterical.online/ for CAN bus setup

#####################################################################
#   CANbus MCUs added for Tridex
#####################################################################

[mcu toolboard_0]
##--------------------------------------------------------------------
canbus_uuid: xxxxxx
##--------------------------------------------------------------------

[mcu toolboard_1]
##--------------------------------------------------------------------
canbus_uuid: xxxxxx
##--------------------------------------------------------------------

[printer]
kinematics: hybrid_corexy           # corexy for standard Trident
max_velocity: 300
max_accel: 4000                     # Max 4000
max_z_velocity: 15                  # Max 15 for 12V TMC Drivers, can increase for 24V
max_z_accel: 350
square_corner_velocity: 5.0

[input_shaper]                      # Leave empty for Tridex

[force_move]
enable_force_move: true

#####################################################################
#   Optional extra klipper features
#####################################################################

[exclude_object]

[idle_timeout]
timeout: 1800

[resonance_tester]
accel_chip: adxl345 toolboard_0
probe_points:
    125, 125, 50                    # 150, 150, 50 for 300 Trident

#####################################################################
#   X Steppers
#####################################################################

[stepper_x] # A stepper - Right for Tridex
step_pin: PC13
dir_pin: !PF0
enable_pin: !PF1
rotation_distance: 40
microsteps: 32
endstop_pin: toolboard_0: PB6
position_min: -50

##--------------------------------------------------------------------
##  Uncomment for 250mm build
#position_endstop: -50   # 250 for standard Trident
#position_max: 225       # 250 for standard Trident, 225 for Standard Tridex.

##  Uncomment for 300mm build
#position_endstop: -50   # 300 for standard Trident
#position_max: 295       # 300 for standard Trident, 275 for Standard Tridex

##  Uncomment for 350mm build
#position_endstop: -50   # 350 for standard Trident
#position_max: 325       # 350 for standard Trident, 325 for Standard Tridex.
##--------------------------------------------------------------------

homing_speed: 60
second_homing_speed: 3
homing_retract_dist: 5

##  Make sure to update below for your relevant driver (2208 or 2209)
[tmc2209 stepper_x] ## Socket stepper_5
uart_pin: PE4
interpolate: false
run_current: 0.8
sense_resistor: 0.110
stealthchop_threshold: 0

[dual_carriage] # B stepper - Left for Tridex
axis: x
safe_distance: 70 #Set to width of your tool head
step_pin: PG0
dir_pin: !PG1
enable_pin: !PF15
rotation_distance: 40
microsteps: 32
endstop_pin: toolboard_1: PB6

##--------------------------------------------------------------------
position_min: 25 # 0 for standard Trident, 25 for standard Tridex
##--------------------------------------------------------------------
##  Uncomment for 250mm build
#position_endstop: 25    # 250 for standard Trident, 25 for standard Tridex
#position_max: 300       # 250 for standard Trident, 300 for standard Tridex

##  Uncomment for 300mm build
#position_endstop: 25    # 300 for standard Trident, 25 for standard Tridex
#position_max: 350       # 300 for standard Trident, 350 for standard Tridex

##  Uncomment for 350mm build
#position_endstop: 25    # 350 for standard Trident, 25 for standard Tridex
#position_max: 400       # 350 for standard Trident, 400 for standard Tridex
##--------------------------------------------------------------------

homing_speed: 60
second_homing_speed: 3
homing_retract_dist: 5

##  Make sure to update below for your relevant driver (2208 or 2209)
[tmc2209 dual_carriage] ## Socket stepper_1
uart_pin: PD11
interpolate: false
run_current: 0.8
sense_resistor: 0.110
stealthchop_threshold: 0

#####################################################################
#   Y Steppers
#####################################################################

[stepper_y] ##  Y Stepper - Left
step_pin: PF13
dir_pin: PF12
enable_pin: !PF14
rotation_distance: 40
microsteps: 32
endstop_pin: ^PG13

##--------------------------------------------------------------------
position_min: 0 # 0 for standard Trident, 0 for standard Tridex
##--------------------------------------------------------------------
##  Uncomment for 250mm build
#position_endstop: 250   # 250 for standard Trident
#position_max: 250       # 250 for standard Trident, 250 for standard Tridex

##  Uncomment for 300mm build
#position_endstop: 300   # 300 for standard Trident
#position_max: 300       # 300 for standard Trident, 300 for standard Tridex

##  Uncomment for 350mm build
#position_endstop: 350   # 350 for standard Trident
#position_max: 350       # 350 for standard Trident, 400 for standard Tridex
##--------------------------------------------------------------------

homing_speed: 60
second_homing_speed: 5
homing_retract_dist: 5

##  Make sure to update below for your relevant driver (2208 or 2209)
[tmc2209 stepper_y] # Socket stepper_0
uart_pin: PC4
interpolate: false
run_current: 0.8
sense_resistor: 0.110
stealthchop_threshold: 0

[stepper_y1] ##  Y Stepper - Right
step_pin: PE2
dir_pin: !PE3
enable_pin: !PD4
microsteps: 32
rotation_distance: 40
endstop_pin: ^PG9

##  Make sure to update below for your relevant driver (2208 or 2209)
[tmc2209 stepper_y1] # Socket stepper_6
uart_pin: PE1
interpolate: false
run_current: 0.8
sense_resistor: 0.110
stealthchop_threshold: 0

#####################################################################
#   Z Steppers
#####################################################################

[stepper_z] # Z0 Stepper - Front Left
step_pin: PF11
dir_pin: PG3
enable_pin: !PG5

##--------------------------------------------------------------------
## Rotation Distance for TR8x8 = 8, TR8x4 = 4, TR8x2 = 2
rotation_distance: 4
##--------------------------------------------------------------------

microsteps: 32

##--------------------------------------------------------------------
#endstop_pin: PG10 # For default endstop pin behind bed
#endstop_pin: probe:z_virtual_endstop # for TAP
##--------------------------------------------------------------------
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

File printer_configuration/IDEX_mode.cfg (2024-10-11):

# This file contains the configuration for independent dual extruder
# printer using dual carriages (an "IDEX" printer).

# See config_Reference.md for a description of parameters.

########################################
# DUAL-CARRIAGES Macros and variables
########################################

[save_variables]
filename: ~/printer_data/config/idex-variables.cfg

[gcode_macro DC_VARS]
# Variables for safe homing, set to z_endstop location pin OR safe location when using TAP
variable_homing_safe_x: 150
variable_homing_safe_y: 150
variable_homing_feedrate: 12000

# Distance from end of axis to park the tool head, needed for x/y offsets, default: 3
# This value must be greater than the X offset between tool heads in order to avoid move out of range errors.
variable_park_distance: 3

# Copy and mirror mode start location for T0, T1 start will be calculated off these values
# This position is where to start the syncronization between the tool heads.
# I recommend placing it near the ending location for your T0 purge.
variable_copy_start_x: 5
variable_copy_start_y: 5
variable_copy_start_z: 5

# Print cooling fans names
variable_fan0: 'print_cooling_t0'
variable_fan1: 'print_cooling_t1'

## Autopark parameters
## default autopark: 0:inactive - 1:active
variable_autopark: 1
variable_z_hop: 1
variable_movespeed: 250
variable_feedrate: 20000

# Nozzle Scrub / Purge
variable_scrub: 1
variable_scrubs: 5
variable_prep_spd_xy: 3000
variable_purge_length: 0
variable_purge_spd: 150
variable_purge_ret: 0
variable_ooze_dwell: 1
variable_purge_temp_min: 200

#####################################################################
#   Variables below here are set in idex-variables.cfg
#   Don't bother changing these, they will be overridden
#####################################################################

# How tool changes should be done, valid values are:
# SWAP Moves both tool heads at the same time, quickest tool change option.
#      Works best with the following custom g-code added to Tool Change:
#      {if wipe_tower}
#      G0 X{wipe_tower_x} Y{wipe_tower_y} F{travel_speed*60} ;move to wipe tower before toolchange
#      {endif}
# CLASSIC Moves tool heads individually, classic Tridex behavior. This is the default value
# OOZE_PREV During tool change, leaves the tool over the parking area while the nozzle re-heats.

# Set the preferred_tool_change in the idex-variables.cfg to one of the following values:
# preferred_tool_change = 'SWAP'
# preferred_tool_change = 'CLASSIC'
# preferred_tool_change = 'OOZE_PREV'

# Variables to store the tool head offsets, leave a 0.0
# Set your offsets in idex-variables.cfg
variable_offset_x: 0.0
variable_offset_y: 0.0
variable_offset_z: 0.0
# These variables are for the tool change method, do not edit
# Set your preferred tool change in idex-variables.cfg
variable_swap_toolheads: 0
variable_immediate_move: 1
# Copy and mirrror mode T1 temperatures - do not edit, these are sent over by the slicer.
variable_t0_copy_mirror_temp_start: 0
variable_t1_copy_mirror_temp_start: 0
variable_t0_copy_mirror_temp_print: 0
variable_t1_copy_mirror_temp_print: 0

gcode:

[respond]

#####################################################################
#   T0 macro
#   In PRIMARY mode activates tool 0, parks tool 1 if enabled.
#####################################################################

[gcode_macro T0]
description: Activate T0 in "FULL_CONTROL" or "AUTO-PARK"
gcode:
    {% set dcvars = printer["gcode_macro DC_VARS"] %}
    {% set tweaked_z_offset = printer.gcode_move.homing_origin.z|round(3)|float %}
    {% set do_scrub = dcvars.scrub|int %}
    {% if printer.dual_carriage is defined %}
        {% if printer.dual_carriage.carriage_0 == "INACTIVE" %}
            # If the printer isn't homed, just change over to the other tool head.
            # This makes loading filament and puging a little easier.
            {% if "xyz" not in printer.toolhead.homed_axes %}
                ACTIVATE_EXTRUDER EXTRUDER=extruder
                SET_DUAL_CARRIAGE CARRIAGE=0
            {% else %}
                # z-hop.
                {% if dcvars.z_hop|float > 0.0 %}
                    {% set max_z = printer.toolhead.axis_maximum.z|float %}
                    {% set cur_z = printer.toolhead.position.z|float %}
                    {% set z_safe = dcvars.z_hop|float if cur_z < (max_z - dcvars.z_hop|float) else (max_z - cur_z) %}
                    G91
                    G1 Z{z_safe}
                    G90
                {% endif %}
                {% if dcvars.swap_toolheads == 1 %}
                    SAVE_GCODE_STATE NAME=swap_state
                    RESPOND TYPE=echo MSG="Swap Change"
                    # Stealthburner LED Section ##
                    #STATUS_READY               #
                     # End LED Section ############
                    _SWAP_T0
                    RESTORE_GCODE_STATE NAME=swap_state
                {% else %}
                    RESPOND TYPE=echo MSG="Classic Change"
                    {% if dcvars.autopark == 1 %}
                        # park tool.
                        SAVE_GCODE_STATE NAME=toolhead_state
                        _PARK_TOOL
                        # Stealthburner LED Section ##
                        #STATUS_READY                #
                        # End LED Section ############
                    {% endif %}
                    # toggle carriage.
                    ACTIVATE_EXTRUDER EXTRUDER=extruder
                    SET_DUAL_CARRIAGE CARRIAGE=0
                    # Scrub the nozzle if enabled.
                    {% if do_scrub == 1 %}
                        _NOZZLE_SCRUB
                    {% endif %}
                    {% if dcvars.autopark == 1 %}
                        RESTORE_GCODE_STATE NAME=toolhead_state MOVE={dcvars.immediate_move} MOVE_SPEED={dcvars.movespeed}
                    {% endif %}
                {% endif %}
                # restore z.
                {% if (z_safe) is defined %}
                    G91
                    G1 Z-{z_safe}
                    G90
                {% endif %}
                # Set the offsets.
                {% if tweaked_z_offset == 0 %}
                  #Z-Offset was cleared when T1 was active, this can cause errors and compound offset if done repeatedly.
                  SET_GCODE_OFFSET X=0 Y=0 Z=0 MOVE=1
                {% else %}
                  SET_GCODE_OFFSET X=0 Y=0 Z={(tweaked_z_offset - dcvars.offset_z)|round(3)} MOVE=1
                {% endif %}
                # print fan speed.
                _SET_PRINT_FANS_SPEED
                # Stealthburner LED Section ##
                #STATUS_PRINTING             #
                # End LED Section ############
            {% endif %}
        {% endif %}
    {% endif %}

#####################################################################
#   _SWAP_T0 macro
#   Change to T0 via quick swap
#   Ported from Helge Keck's Vcore IDEX macros.
#####################################################################

[gcode_macro _SWAP_T0]
description: Perform toolhead swap for T0
gcode:
    {% set dcvars = printer["gcode_macro DC_VARS"] %}
    # Get position of both tool heads.
    {% set t0_curr_pos = printer.configfile.config.stepper_x.position_endstop|float + dcvars.park_distance %}
    {% set t1_curr_pos = printer.gcode_move.gcode_position.x|float %}
    {% set t0_new_x = t1_curr_pos %}
    {% set t1_new_x = printer.configfile.config.dual_carriage.position_max|float - dcvars.park_distance %}
    {% set t0_distance = t0_new_x - t0_curr_pos %}
    {% set t1_distance = t1_new_x - t1_curr_pos %}
    # If T0 is moving further or the same as T1.
    {% if t0_distance >= t1_distance %}
        # Set mode to copy.
        SET_DUAL_CARRIAGE CARRIAGE=1 MODE=COPY
        # Perform the copy mode move.
        G0 X{t0_curr_pos + t1_distance} F{dcvars.feedrate}
        # Remove T1 from copy mode.
        SET_DUAL_CARRIAGE CARRIAGE=1 MODE=PRIMARY
        # Finish moving T0 into position.
        SET_DUAL_CARRIAGE CARRIAGE=0 MODE=PRIMARY
        G0 X{t0_new_x} F{dcvars.feedrate}
    # if T0 is moving less than T1.
    {% elif t0_distance < t1_distance %}
        # Set mode to copy.
        SET_DUAL_CARRIAGE CARRIAGE=1 MODE=COPY
        # Perform the copy mode move.
        G0 X{t0_new_x} F{dcvars.feedrate}
        # Finish moving T1.
        SET_DUAL_CARRIAGE CARRIAGE=1 MODE=PRIMARY
        G0 X{t1_new_x} F{dcvars.feedrate}
        # Set the active carriage to T0.
        SET_DUAL_CARRIAGE CARRIAGE=0 MODE=PRIMARY
    {% endif %}
    ACTIVATE_EXTRUDER EXTRUDER=extruder

#####################################################################
#   T1 macro
#   In PRIMARY mode activates tool 1, parks tool 0 if enabled.
#####################################################################
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

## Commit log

2023-12-05 Added adjustable carriage
    [ac_lever.stl, ac_tool_mount_left.stl, ac_tool_mount_right.stl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]
2023-12-05 Added Dragon Burner cowls
    [t0_cat_cowl.stl, t0_cat_cowl_ear_insert.stl, t0_cat_cowl_hex_insert.stl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]
2023-12-05 Added printer and slicer configurations, Dec 4, 2023
    [IDEX_mode.cfg, frame_and_rails_calc.ods, homing_override_for_idex.cfg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]
2023-12-10 Bugfix - tool change preference not loading properly
    Fixed a bug where the tool change preference would not load properly
    Added a macro to display current T1 offsets
    [IDEX_mode.cfg]
2023-12-17 Update IDEX_mode.cfg
    Corrected z_offset_decrease001 to adjust the correct 0.01mm
    [IDEX_mode.cfg]
2023-12-17 Update macros.cfg
    removed unnecessary M221 command.
    [macros.cfg]
2023-12-24 Updated frame calculator to include user specified Z height
    [frame_and_rails_calc.ods]
2024-01-02 Updated T1 offset adjustment macros.
    [IDEX_mode.cfg]
2024-01-04 Added drive frames with umbilical mounts
    [drive_frame_umbilical_mount.step, drive_frame_umbilical_mounts_left.3mf, drive_frame_umbilical_mounts_right.3mf]
2024-01-05 Fixed size of zip tie holes
    [drive_frame_umbilical_mount.step, drive_frame_umbilical_mounts_left.3mf, drive_frame_umbilical_mounts_right.3mf]
2024-01-14 Fixed right drive frame umbilical mount threads, are no longer mirrored
    [drive_frame_umbilical_mount.step, drive_frame_umbilical_mounts_right.3mf]
2024-01-17 Update macros.cfg, removed z0 location from purge_t1
    [macros.cfg]
2024-03-11 Bug Fix: Corrected z_hop on tool change
    Z hop now works with Classic and Swap tool changes, also returns to the proper z height when returning to the print.
    [IDEX_mode.cfg]
2024-03-12 Bug Fix: Decreasing z offset macros will now decrease the z offset
    [IDEX_mode.cfg]
2024-03-12 Moved extruder PID setting to printer.cfg
    [printer.cfg]
2024-03-13 Corrected status_leveling macro typo
    [sbled_effects_barf_idex.cfg]
2024-03-15 Bug fix: if T1 printed first, would move out of range
    [macros.cfg]
2024-03-17 Update start g-code for PRIMARY mode printing.
2024-03-18 Big update, macros and more
    Updated macros, slicer settings, added filament runout sensors and more.
    [IDEX_mode.cfg, [a]_bowden_clip_x3.stl, [flex]_bowden_clip_bushing_x3.stl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]
2024-03-19 Added sections for tool head lighting, uncomment if desired
    [macros.cfg]
2024-03-20 Bugfix: T1 z_offset not applied correctly at start of print.
    [macros.cfg]
2024-03-28 M600 support and better rollover macros
    [IDEX_mode.cfg, filament_macros.cfg, homing_override_for_idex.cfg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]
2024-03-28 Fixed typo in M600 macro
    [filament_macros.cfg]
2024-04-03 fixed typo in print_start
    [macros.cfg]
2024-04-08 Update to current klipper dual_carriage
    [sbled_effects_barf_idex.cfg]
2024-04-24 Updated / fixed config, added z adjuster
    [IDEX_mode.cfg, hardware_z_adjuster.step, hardware_z_adjuster.stl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]
2024-04-24 add assembly images
2024-04-24 Removed "max_accel_to_decel" to keep up to date with Klipper
    [printer.cfg]
2024-05-05 Added zero_reference_position to [bed_mesh]
    [printer.cfg]
2024-07-04 update frame and rails calc
    [frame_and_rails_calc.ods]
2024-07-11 Update filament_macros.cfg, correct spelling errors
    [filament_macros.cfg]
2024-09-28 docs: update README.md
    sswitches -> switches
2024-10-11 Buffix and small update
    [IDEX_mode.cfg, homing_override_for_idex.cfg, klicky-probe-for_VT.cfg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]
2024-10-11 I have no idea how git works sometimes
    [IDEX_mode.cfg]
2024-10-14 Added probe include file comments
    [printer.cfg]
2024-12-21 Update of slicer profiles to current versions
